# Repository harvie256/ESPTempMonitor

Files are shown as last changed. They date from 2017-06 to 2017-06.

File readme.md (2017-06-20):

## Synopsis

Battery powered ESP 8266 board with low quiecent voltage regulator, battery voltage measurement, DS18B20 header and LED.

Uses a ESP-07 module to allow both on-module and external antenna.

PCB design is in Altium CircutStudio.

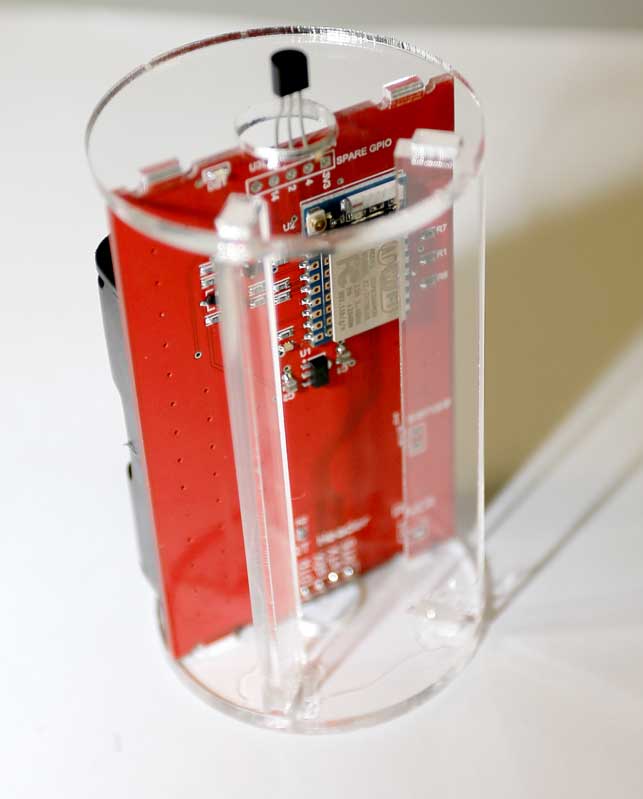
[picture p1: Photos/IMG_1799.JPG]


## Code Example

See Arduino folder.  The contents of the data subdirectory needs to be loaded into SPIFFs along with the main code flashing.

## Tests

Current hardware tests have confirmed functionality of all designed items.

TODO - Power consumption and wifi range.

## License

Public Domain

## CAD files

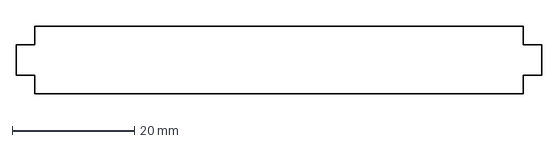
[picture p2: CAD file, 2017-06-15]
LaserCutAcrylic/Sides.dxf
86.0 x 11.0 mm

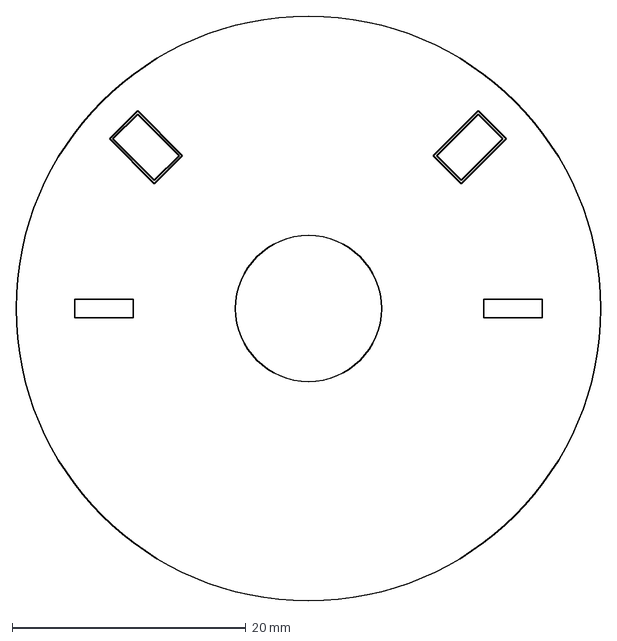
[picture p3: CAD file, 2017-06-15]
LaserCutAcrylic/TopAndBottom.dxf
50.0 x 50.0 mm

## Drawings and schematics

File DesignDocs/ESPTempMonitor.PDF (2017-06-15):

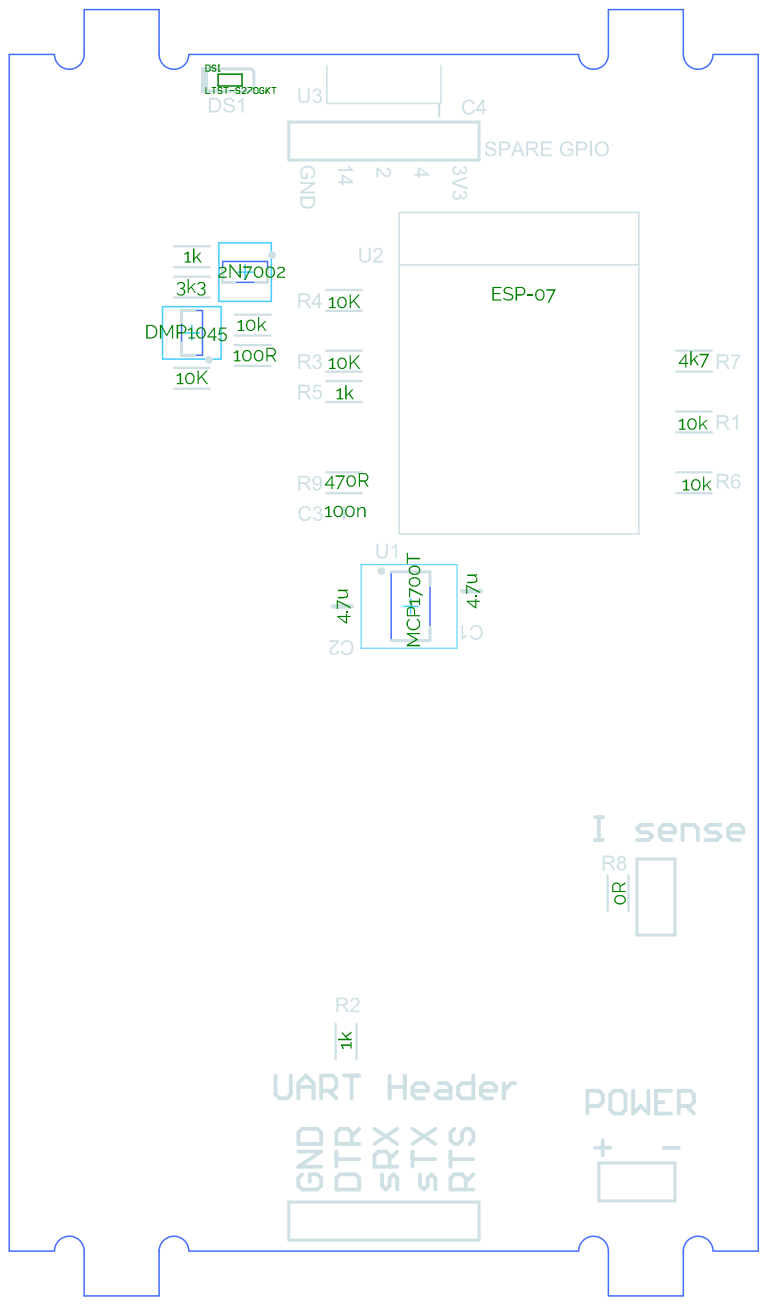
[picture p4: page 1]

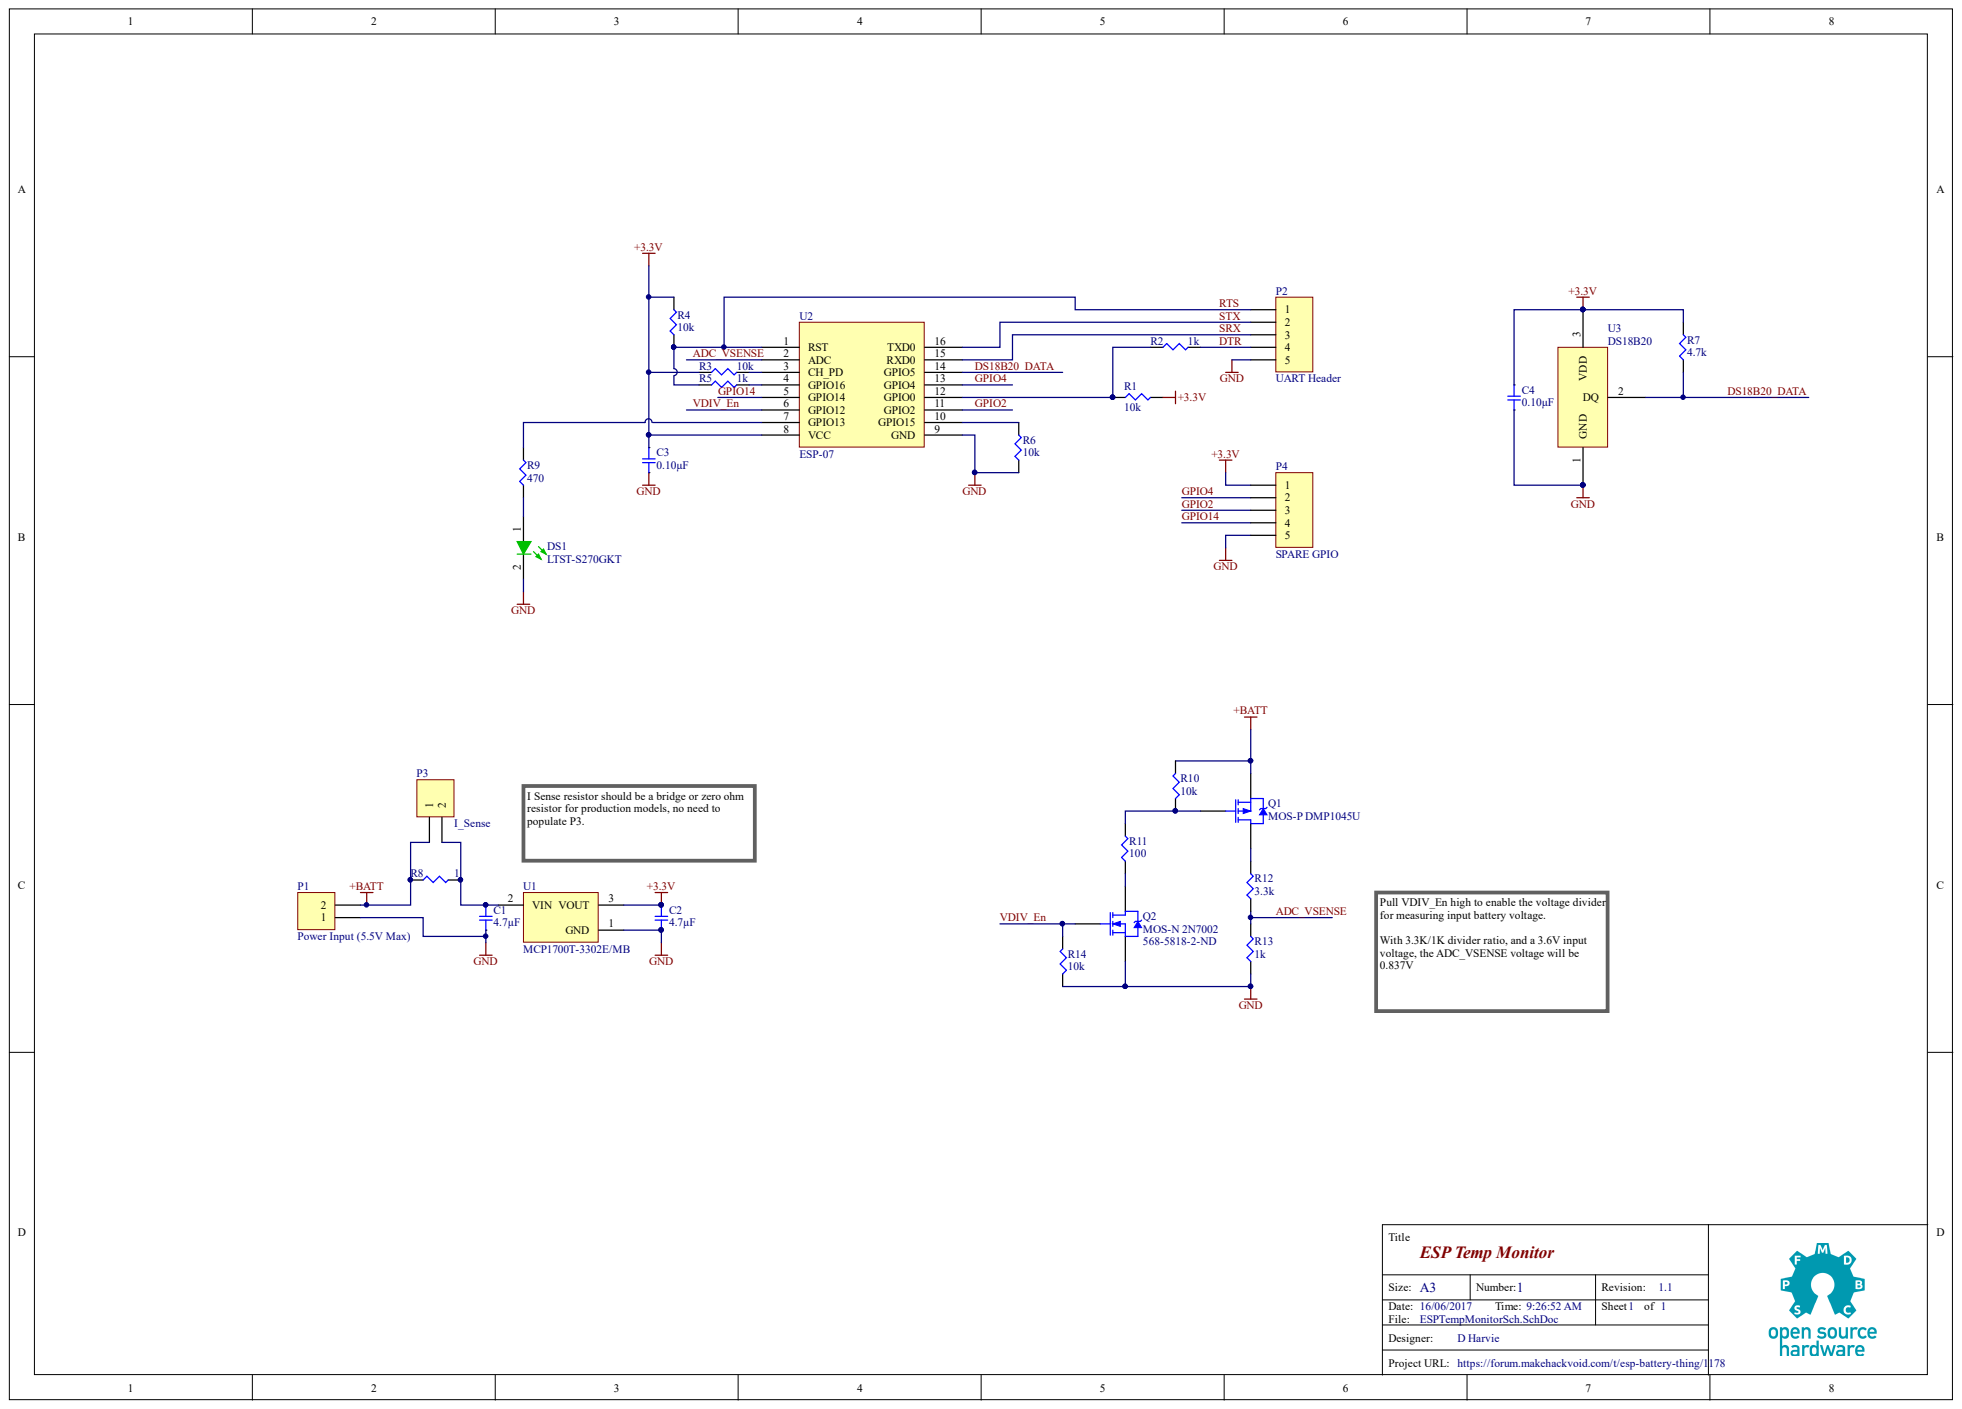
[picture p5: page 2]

tor should be a br
ion model

idge or zero ohm
s, no need to

V_En high to enable the vol

Size: A 3 | Number : 1 | Revi s ion: 1.1
Date: 16/06/2017 Ti me: 9:26:52 A M Fi le: ESPTempMoni torSch.SchDoc | | Sheet 1 of 1

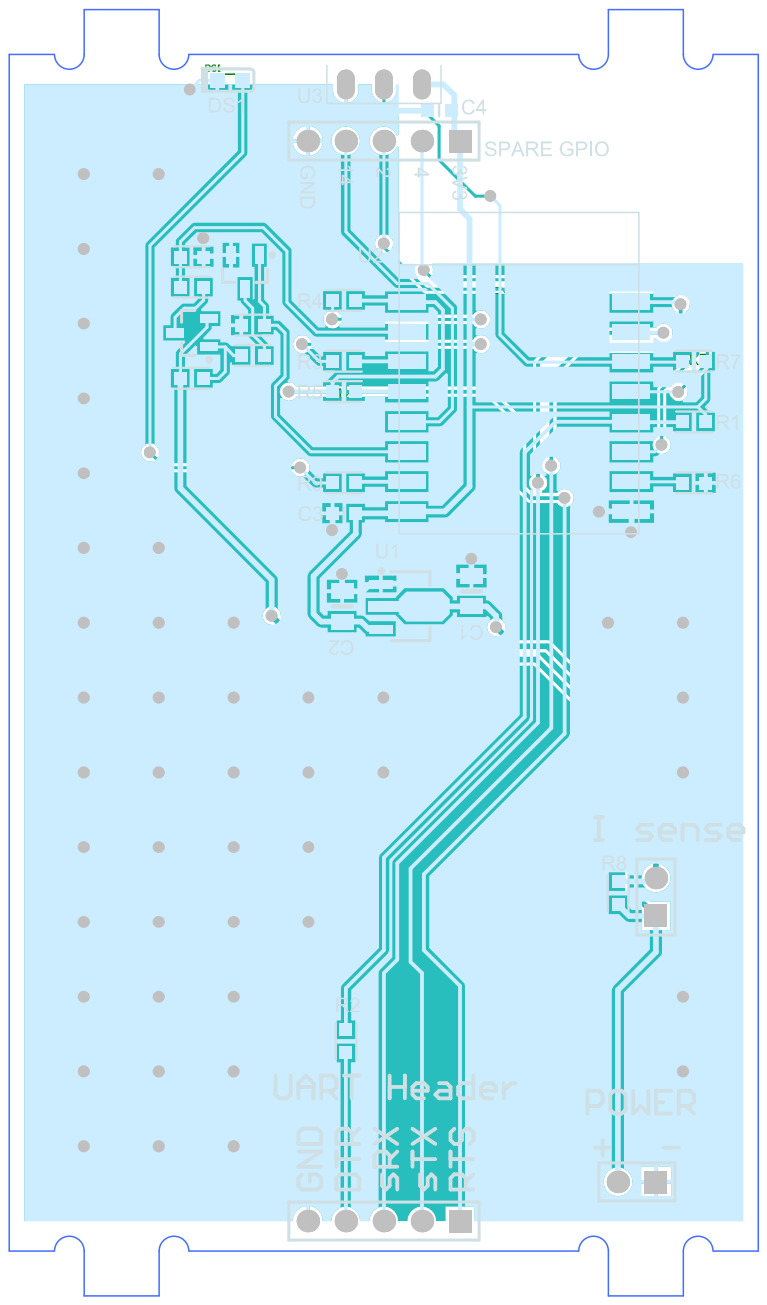
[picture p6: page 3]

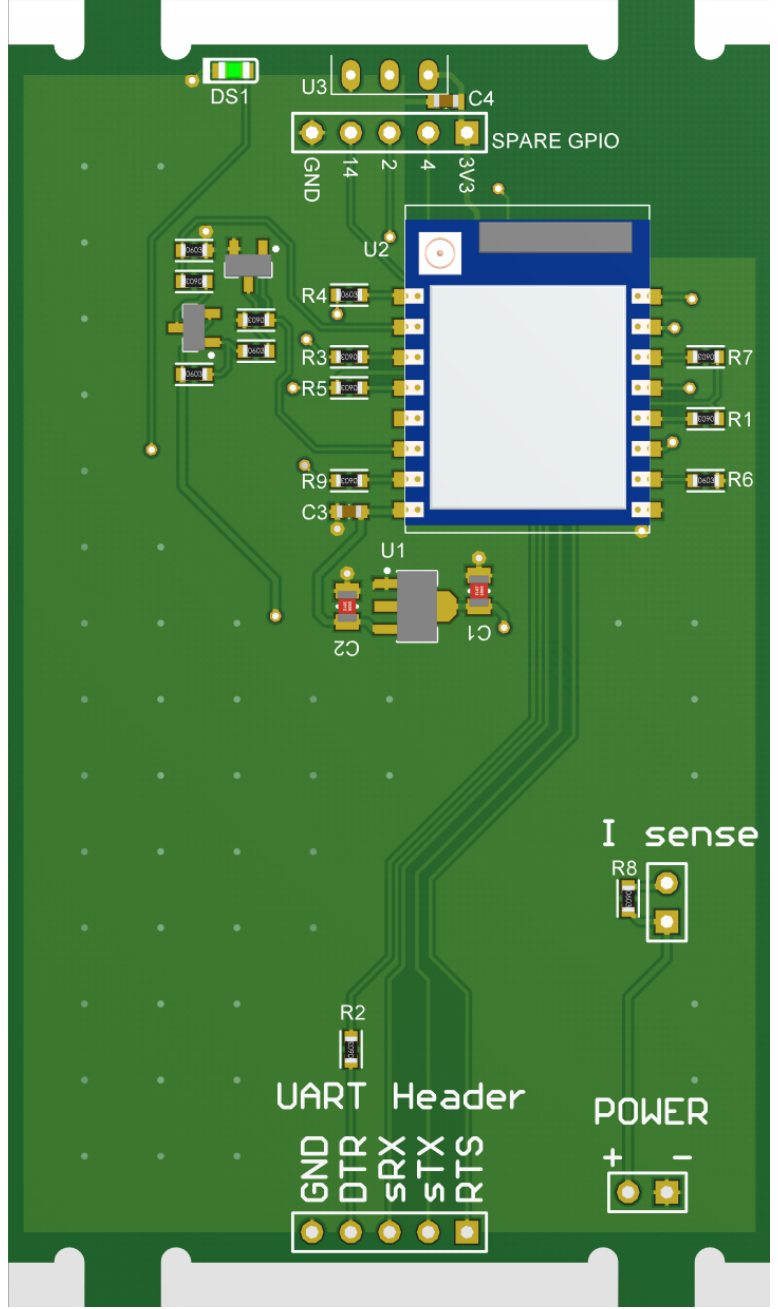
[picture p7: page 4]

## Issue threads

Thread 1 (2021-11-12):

Corrupt PCBDoc File?

GeorgeIoak, 2021-11-12:
I know this is a really old project but I was going to use up some old modules I found and thought I'd borrow your footprint and 3D model for the ESP-07. You have the name as ESPTempMonitor.CSPcbDoc and just renaming to ESPTempMonitorCS.PcbDoc would not stop the error when Altium tried to open the file.

I saw in your project file you had created libraries for this project so even those would work for me.

Thanks in advance,
George

harvie256, 2021-11-13:
These are Altium Circuit Studio pcb files, not Altium Designer.

What are you trying to open them with?

GeorgeIoak, 2021-11-14:
Oh sorry, I was using AD, sorry about that but thanks for following up.

Closed 2021-11-14.

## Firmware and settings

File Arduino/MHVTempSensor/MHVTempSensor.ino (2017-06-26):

#include <ESP8266WebServer.h>
#include <FS.h>
#include <OneWire.h>
#include <DallasTemperature.h>
#include <ArduinoJson.h>
#include <Ticker.h>

#include "constants.h"

/*
 *  Boot mode, either into the config interface or temp sensing programing, 
 *  is determined by a value in the RTC memory.  The RTC memory will keep
 *  its value across deep sleep, but will reset when power is lost.
 *  
 *  Therefore by removing power (i.e. pulling out the batteries), the ESP
 *  will reboot into the config interface.  A timer will then expire if no
 *  web requests are made to start the reading loop.
 * 
 */
bool bootModePowerOn;

/*
 * A seperate timer is being used as a 'watchdog' to prevent system lockup
 * where one of the SDK functions is feeding the watchdog in an infinite loop.
 * See: https://github.com/esp8266/Arduino/issues/1532
 * 
 * Instead of treating it as a normal watchdog, it's being setup as a one-shot
 * affair with a timeout a few times longer than the normal data send loop time.
 */
Ticker tickerOSWatch;

void IsBootPowerOn()
{
  #ifdef DEBUG
    Serial.println(ESP.getResetReason());
  #endif
  bootModePowerOn = ESP.getResetReason().startsWith("External");
}

void ICACHE_RAM_ATTR osWatch(void) {
  ESP.reset();  // hard reset
}

void setup() {
  // Common setup for both modes of operation
  setupIO();
  Serial.begin ( 115200 );

  #ifdef DEBUG
  digitalWrite(DEBUG_PIN_1, HIGH);
  digitalWrite(DEBUG_PIN_2, HIGH);
  #endif

  IsBootPowerOn();
  if(bootModePowerOn){
    WebServerSetup();
  }else {
    tickerOSWatch.attach_ms(OSWATCH_RESET_TIME  * 1000, osWatch);
    MainProgSetup();
  }
}

void loop() {
  if(bootModePowerOn){
    WebServerLoop();
  }else{
    MainProgLoop();
  }
}

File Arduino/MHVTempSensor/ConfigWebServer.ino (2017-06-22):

ESP8266WebServer server ( 80 );


#include <ESP8266WebServer.h>
#include <FS.h>
#include <OneWire.h>
#include <DallasTemperature.h>
#include <ArduinoJson.h>
#include "constants.h"

#define ledToggleIntervalMs 500
#define tempIntervalMs 5000

#define PASSWORD  "password"      // WiFi password

extern float temp;
extern float batteryVoltage;

#define ConfigurationServerTimeout 60000
bool ConfigurationServerTimeoutEnabled = 0;

void generateAndSendJson(){
  char sendBuffer[512];
  DynamicJsonBuffer jsonBuffer(512);
  File f = SPIFFS.open("/config/webcfg.txt", "r");
  if (!f) {
    // TODO Error handle there not being a config file...
    Serial.println("file open failed");
    return;
  }
  JsonObject& root = jsonBuffer.createObject();
  root["SSID"] = readLineAndTrim(f);
  root["password"] = "";
  f.readStringUntil('\n'); // Will not send back password...
  root["ipAddress"] = readLineAndTrim(f);
  root["netmask"] = readLineAndTrim(f);
  root["gateway"] = readLineAndTrim(f);
  root["apikey"] = readLineAndTrim(f);
  root.printTo(sendBuffer, sizeof(sendBuffer));
  server.send(200, "application/json", sendBuffer);
  f.close();
}

void processWebConfigSave(){
  DynamicJsonBuffer jsonBuffer(512);
  JsonObject& root = jsonBuffer.parseObject(server.arg("plain"));
  File f = SPIFFS.open("/config/webcfg.txt", "w");
  if (!f) {
      // TODO Error handle there not being a config file...
      Serial.println("file open failed");
  }

  f.println(root["SSID"].as<String>());
  f.println(root["password"].as<String>());
  f.println(root["ipAddress"].as<String>());
  f.println(root["netmask"].as<String>());
  f.println(root["gateway"].as<String>());
  f.println(root["apikey"].as<String>());
  f.close();

  server.send(200, "text/plain", "");
}

void WebServerSetupWiFi()
{
  WiFi.mode(WIFI_AP);

  char AP_Name[32];
  sprintf (AP_Name, "MHV Sensor %08X", ESP.getChipId());
  WiFi.softAP(AP_Name, PASSWORD);
}


void WebServerSetup() {

  WebServerSetupWiFi();
  
  if (!SPIFFS.begin())
  {
    // TODO Needs error handling...
    Serial.println("SPIFFS Mount failed");
  } else {
    Serial.println("SPIFFS Mount succesfull");
  }

  server.serveStatic("/js", SPIFFS, "/js", "max-age=86400");
  server.serveStatic("/html", SPIFFS, "/html");
  server.serveStatic("/css", SPIFFS, "/css", "max-age=86400");
  server.serveStatic("/", SPIFFS, "/html/index.html");

  server.on("/sensor", [](){
    ConfigurationServerTimeoutEnabled = 0; // This will get called automatically when the index page is opened.  There probably is a cleaner way in code to set this.
    server.send(200, "application/json", "{ \"BatteryVoltage\": " + String(batteryVoltage,2) + ", \"Temperature\": "+String(temp,2)+" }");
  });

  server.on("/config", HTTP_GET, generateAndSendJson);
  server.on("/config", HTTP_POST, processWebConfigSave);
  server.on("/reset", [](){ESP.reset(); });
  


  server.onNotFound([](){
      server.send(404, "text/plain", "FileNotFound");
  });

  server.begin();
  Serial.println ( "HTTP server started" );

  // Check if webcfg file exists, if not there's no point restarting to run mode
  ConfigurationServerTimeoutEnabled = SPIFFS.exists("/config/webcfg.txt");

}

void WebServerLoop() {
  static unsigned long ledTimer = 0;
  static unsigned long tempTimer = 0;

  server.handleClient();

  if(millis() > ledTimer)
  {
    ledTimer = millis() + ledToggleIntervalMs;
    if(digitalRead(LED_PIN))
      digitalWrite(LED_PIN, LOW);
    else
      digitalWrite(LED_PIN,HIGH);
  }

  if(millis() > tempTimer)
  {
    tempTimer = millis() + tempIntervalMs;

    updateBatteryVoltage();
    updateTemperature();

  }

  if(ConfigurationServerTimeoutEnabled && (millis() > ConfigurationServerTimeout))
  {
      ESP.reset();
  }
  
}

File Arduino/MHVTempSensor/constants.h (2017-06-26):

#define VDIV_EN_PIN 12
#define LED_PIN 13
#define DS18B20_PIN 5

#define ADC_CAL (3.68/812.0)

#define OSWATCH_RESET_TIME 10

// Define DEBUG to enable serial printing and toggling debug pins for timing
#define DEBUG

#ifdef DEBUG
#define DEBUG_PIN_1 2
#define DEBUG_PIN_2 4
#endif

  

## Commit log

2017-06-15 Initial PCB check-in
    [ESPTempMonitor.PrjPcb, ESPTempMonitorSch.SchDoc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]
2017-06-15 Added acrylic files
    [Sides.dxf, TopAndBottom.dxf]
2017-06-20 First check in of Arduino Web Server code
2017-06-22 Bug fixes and changed to HTTP GET from POST
    Reduces time from ~5 sec to 2-2.5 sec for an update cycle.
    [CommonFunctions.ino, ConfigWebServer.ino, MHVTempSensor.ino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]
2017-06-26 Added timer watchdog function
